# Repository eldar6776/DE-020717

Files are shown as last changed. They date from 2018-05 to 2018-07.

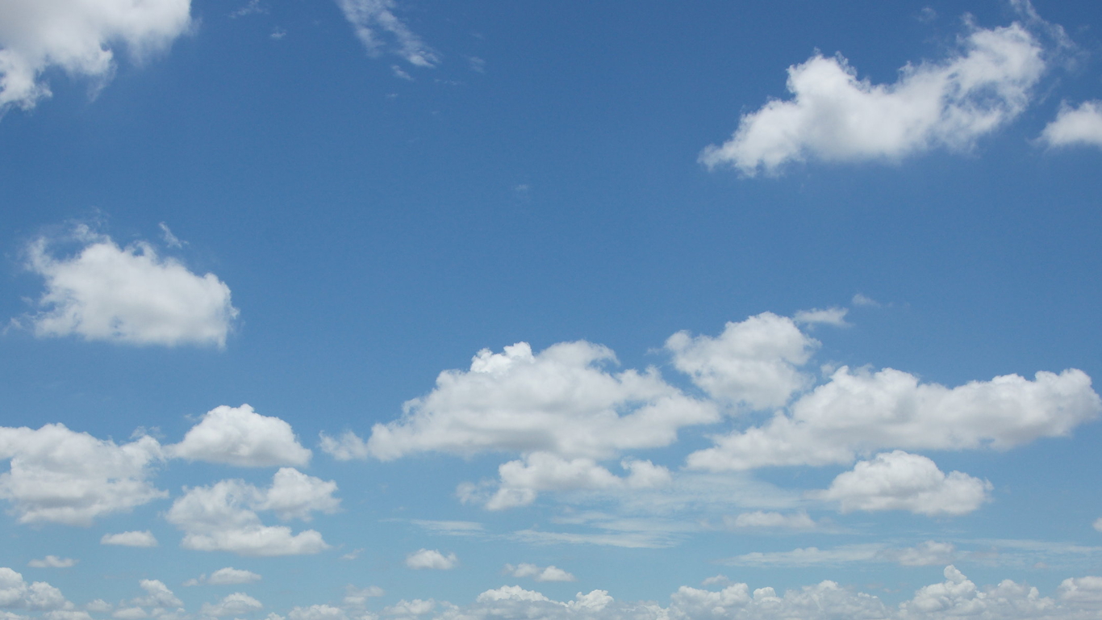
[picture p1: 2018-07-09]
doc/thermostat_gui_image/weather_cloudy_2.jpg

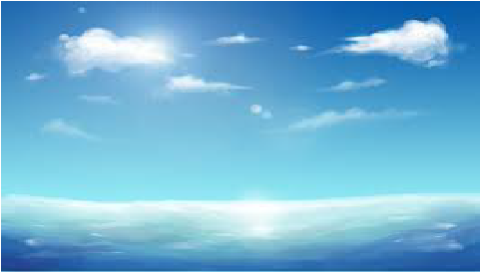
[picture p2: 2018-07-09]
doc/thermostat_gui_image/background.bmp

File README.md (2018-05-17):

# DE-020717
	Hotel Room Thermostat With Capacitive Touch 4,3" TFT LCD And Audio Codec

/**
 ******************************************************************************
 * Project Name         : DE-020717
 * Date			: 02.07.2017.
 * Hardware IDE         : Altium Designer 16.0.5
 * Firmware IDE         : KEIL uVision 5.25.0.0
 * Target Device        : STM32F746ZET  (LQFP-144, 512 Kbytes Flash, 216 MHz)
 ******************************************************************************
 * 
 * Feature		: Hardware 	
 * ----------------------------------------------------------------------------
 *	
 *	1 OneWire Serial Port For Connection With Room Control Bus Or Digital Sensors
 *	1 RS485 Serial Port For Connection With Hotel Control Bus
 *	6 Digital Otputs 0,5A 50V For Fancoil Control
 *	2 High Speed Digital Inputs Sensing Mains Phase Zero Crossing And Fan RPM
 *	3 Analog Inputs For Temperature And Light Sensing
 *	Audio Codec With Wave Player And 1W Speacker Amplifier Is Used For Audio Signal
 *	2,4GHz Radio Transciever 1Mbps For Wireless Connection To Control Network
 *	Battery Connector For RTC Backup 
 *	5Vdc Or 12Vdc Power Supply
 *	"DE-060418" Or "DE-130418" Is Used As Fancoil Interface
 *	"DE-200216" Or "DE-290817" Is Used As Room Controller 
 *	"Red Dragon 429 Demo Board" Is Used As Hotel Controller
 *
 * ----------------------------------------------------------------------------
 *	
 *			: Firmware
 * ----------------------------------------------------------------------------
 *	
 *	Room Temperature Set, Ambient Temperature Monitoring, Fancoil Fan Speed
 *	In 3 Manual Presets (Lo, Mid, Hi). Automatic Fancoil Fan Speed With PID 
 *	Control Loop When Fancoil Fan Motor Is Equipped With RPM Sensor And  
 *	Triac Is Used For Phase Control Of Fan Motor AC Power Supply. When 3 Speed
 *	Fancoil Fan Motor Is Used, Proportional Controller Is Activ In Automatic Mode.
 *	Set Thermostat For Cooling Or Heating. Software One Cycle Function Activation
 * 	Used For Room Preheating Or Precooling To Comfortable Temperature.
 *	7 Days Wheter Forecast Info Screen. Alarm Clock With One Preset.
 *	Button For "Do Not Disturb" Function Activation / Deactivation. Message Is 
 *	Displayed On Outdoor Room Controller Display And Doorbell Is Disabled.
 *	Button For "Call Handmaid" Activation / Deactivation. Signal Is Activated
 *	On Outdoor Room Controller Display And Call Is Send To Reception PC Software
 *	Button For "SOS Reset" When SOS Alarm Is Activated By Pulling SOS Switch In
 *	Bathroom.
 *
 * ----------------------------------------------------------------------------
 *
 ******************************************************************************
 */

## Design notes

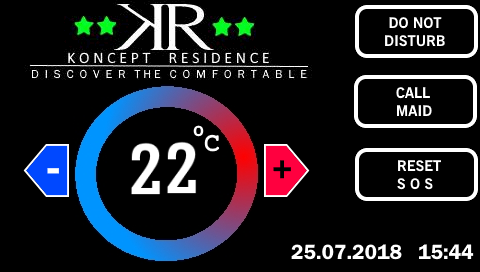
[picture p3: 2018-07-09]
doc/new_gui_image/primjer.bmp

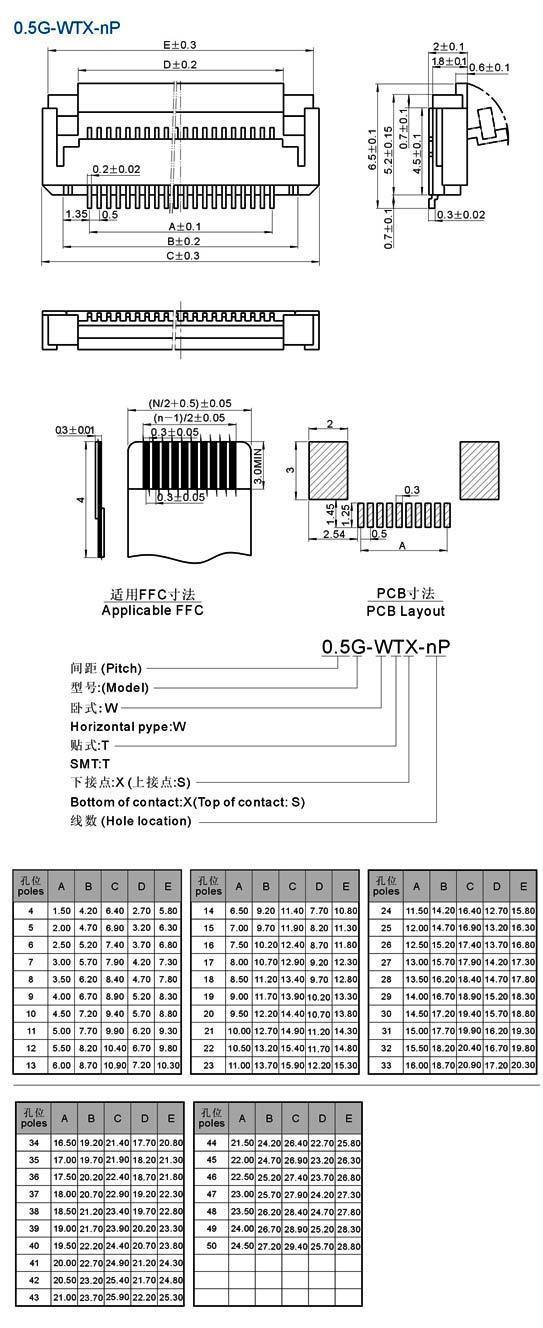
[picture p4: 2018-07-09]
doc/FPC10_Connector.jpg

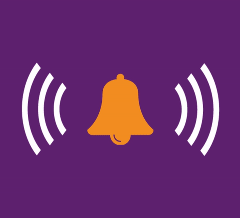
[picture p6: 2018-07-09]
doc/thermostat_gui_image/doorbell.gif

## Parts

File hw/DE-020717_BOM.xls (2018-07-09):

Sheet: BOM Report
Bill of Materials |  |  | Bill of Materials For PCB Document [DE-020717.PcbDoc]
Source Data From: |  | DE-020717.PcbDoc
Project: |  | DE-020717.PrjPcb
Variant: |  | None
Creation Date: | 2.6.2018. | 16:11:59
Print Date: | 43253 | 43253.67921
Footprint | Comment | LibRef | Designator | Description | Quantity
0603 | 100nF | C0603 | C1, C2, C3, C4, C5, C6, C7, C8, C12, C13, C14, C15, C16, C17, C19, C20, C21, C22, C23, C24, C25, C26, C27, C28, C30, C31, C32, C33, C34, C36, C37, C38, C39, C40, C41, C42, C44, C45, C46, C48, C49, C50, C51, C53, C55, C56, C66, C68, C71, C72, C74, C75, C79 | Ceramic Chip Capacitor - Standard | 59
0805 | C0805 | C0805 | C9, C10, C35 | Ceramic Chip Capacitor - Standard | 3
0603 | C0603 | C0603 | C11, C18, C29, C43, C47, C52 | Ceramic Chip Capacitor - Standard | 6
0805 | 4u7 | C0805 | C54, C57, C70, C73, C81 | Ceramic Chip Capacitor - Standard | 5
0603 | 1uF | C0603 | C67 | Ceramic Chip Capacitor - Standard | 1
3528 | 22uF/16V | 293D156X0004B2 | C83, C84 | Tantamount Commercial, Surface Mount Solid Tantalum Chip Capacitor: 15uF, 20% Tolerance, 4 WVDC @ +85°C, Surge = 5.2V | 2
3528 | 47uF/10V | 293D156X0004B2 | C85, C86 | Tantamount Commercial, Surface Mount Solid Tantalum Chip Capacitor: 15uF, 20% Tolerance, 4 WVDC @ +85°C, Surge = 5.2V | 2
3528 | 100uF | 293D156X0004B2 | C87 | Tantamount Commercial, Surface Mount Solid Tantalum Chip Capacitor: 15uF, 20% Tolerance, 4 WVDC @ +85°C, Surge = 5.2V | 1
0805 | 10uF | C0805 | C90, C93, C94 | Ceramic Chip Capacitor - Standard | 3
1.6X0.8X0.8A | HSMH-C190 | HSMH-C190 | D1 | Surface Mount Chip LED, Red | 1
ONSC-SOD-123-2-425-04_V | STPS1L40M | SMMSD301T1G | D2 | Schottky Barrier Diode, 2-Pin SOD-123, Pb-Free, Tape and Reel | 1
0603 | BLM15AG121 | Inductor_SMD | L1, L2, L3, L5, L7, L8, L9, L10 | Inductor | 8
WE-LQS 252012 | 4,7uH SMD Inductor | SMD inductor | L4 | WE-LQS SMD Power Inductor, L=4.7 µH | 1
HDR1X2 | 3VBAT | NOT FEEDED | P1 | Header, 2-Pin | 1
HDR1X2 | AMBIENT_LIGHT | NOT FEEDED | P2 | Header, 2-Pin | 1
HDR1X2 | AMBIENT_TEMPERATURE | NOT FEEDED | P3 | Header, 2-Pin | 1
10 pin PFC | TOUCH_SCREEN | TS_Connector | P4 | 10 pin PFC connector bottom contacts | 1
HDR2X4 | nRF24L01 | NOT FEEDED | P7 | Header, 4-Pin, Dual row | 1
40 pin FPC | 480x272 RGB TFT LCD AML043056B0-40 | TFT LCD Connector | P8 | 40 pin pfc connector bottom contacts | 1
HDR1X3 | ST-Link Debbuger | NOT FEEDED | P9 | Header, 3-Pin | 1
HDR2X5 | EXPAND | NOT FEEDED | P10 | Header, 5-Pin, Dual row | 1
HDR1X8 | FANCOIL_INTERFACE | NOT FEEDED | P11 | Header, 8-Pin | 1
HDR1X8 | POWER_&_COM | NOT FEEDED | P12 | Header, 8-Pin | 1
SOT23_N | 2N7002 | 2N7002 | Q1, Q2, Q3, Q4 | N-channel Enhancement Mode Vertical D-MOSFET | 4
2-0402 | 10K | ERJ2GE | R1, R2, R3, R4, R5, R6, R7, R8, R9, R10, R11, R14, R15, R16, R17, R18, R19, R20 | Thick Film Chip Resistor, 1 Ohm to 2.2M Ohm Range, 5% Tolerance, 0402 Size, 0.063 W | 18
ERA-0603 | 10K | ERA3Y | R12, R13, R22, R28, R39, R60, R61 | Rectangular Thick Film Chip Resistor, 10 Ohm to 330k Ohm Range, 0.1% and 0.5% Tolerance, 0603 Size, 0.063 W | 7
ERA-0603 | 2K7 | ERA3Y | R21, R23, R25, R26 | Rectangular Thick Film Chip Resistor, 10 Ohm to 330k Ohm Range, 0.1% and 0.5% Tolerance, 0603 Size, 0.063 W | 4
ERA-0603 | 0R | ERA3Y, ERA3Y, ERA3Y, ERA3Y, ERA3Y, ERAV | R24, R27, R34, R36, R37, R48 | Rectangular Thick Film Chip Resistor, 10 Ohm to 330k Ohm Range, 0.1% and 0.5% Tolerance, 0603 Size, 0.063 W, Rectangular Thick Film Chip Resistor, 10 Ohm to 330k Ohm Range, 0.1% and 0.5% Tolerance, 0603 Size, 0.063 W, Rectangular Thick Film Chip Resistor, | 6
ERA-0603 | 560R | ERA3Y | R29, R41 | Rectangular Thick Film Chip Resistor, 10 Ohm to 330k Ohm Range, 0.1% and 0.5% Tolerance, 0603 Size, 0.063 W | 2
ERA-0603 | 1K | ERA3Y | R30, R42, R43 | Rectangular Thick Film Chip Resistor, 10 Ohm to 330k Ohm Range, 0.1% and 0.5% Tolerance, 0603 Size, 0.063 W | 3
ERA-0603 | 330R | ERA3Y | R31 | Rectangular Thick Film Chip Resistor, 10 Ohm to 330k Ohm Range, 0.1% and 0.5% Tolerance, 0603 Size, 0.063 W | 1
ERA-0603 | NF | ERA3Y | R32, R33, R38 | Rectangular Thick Film Chip Resistor, 10 Ohm to 330k Ohm Range, 0.1% and 0.5% Tolerance, 0603 Size, 0.063 W | 3
ERA-0603 | 220R | ERA3Y | R35, R44 | Rectangular Thick Film Chip Resistor, 10 Ohm to 330k Ohm Range, 0.1% and 0.5% Tolerance, 0603 Size, 0.063 W | 2
ERA-0603 | 2K2 | ERA3Y, ERAV, ERAV, ERAV, ERAV, ERAV, ERA3Y | R40, R51, R52, R53, R54, R55, R59 | Rectangular Thick Film Chip Resistor, 10 Ohm to 330k Ohm Range, 0.1% and 0.5% Tolerance, 0603 Size, 0.063 W, Metal Film Thermosensitive Chip Resistor, 0.56 Ohm to 10k Ohm Range, 5% Tolerance, 0603 Size, 0.063 W, Metal Film Thermosensitive Chip Resistor, 0 | 7
ERA-0603 | 100K | ERAV | R45 | Metal Film Thermosensitive Chip Resistor, 0.56 Ohm to 10k Ohm Range, 5% Tolerance, 0603 Size, 0.063 W | 1
ERA-0603 | 4K7 | ERAV, ERA3Y | R46, R58 | Metal Film Thermosensitive Chip Resistor, 0.56 Ohm to 10k Ohm Range, 5% Tolerance, 0603 Size, 0.063 W, Rectangular Thick Film Chip Resistor, 10 Ohm to 330k Ohm Range, 0.1% and 0.5% Tolerance, 0603 Size, 0.063 W | 2
ERA-0805 | 10R | ERAS | R47 | Metal Film Thermosensitive Chip Resistor, 0.56 Ohm to 10k Ohm Range, 5% Tolerance, 0805 Size, 0.1 W | 1
ERA-0603 | 1K2 | ERA3Y | R57 | Rectangular Thick Film Chip Resistor, 10 Ohm to 330k Ohm Range, 0.1% and 0.5% Tolerance, 0603 Size, 0.063 W | 1
LQFP-144_20X20mm | STM32F746ZET | STM32F74XZXT | U1 | STM32F746ZET ARM Cortex M7 microcontroller | 1
MICT-P-86_N | MT48LC4M32B2P-6A | MT48LC4M32B2P-6A | U2 | 128Mb PC133 SDR SDRAM, 4Mb x 32, 6ns, 3.3V, 0 to 70 degC, 86-Pin TSOP, Pb-Free | 1
419A-01_N | MC74VHC1GT14DFT1 | MC74VHC1GT14DFT1 | U3, U5 | Schmitt-Trigger Inverter / Logic Level Shifter with LSTTL-Compatible Inputs | 2
SO16_N | ULN2003A | ULN2003D | U4 | Seven Darlington Array | 1
QFN8_V | STLD40DPUR | STLD40DPUR | U6 | White Led Power Supply For Large Display Backlight, 8-Pin VFDFPN, Tape and Reel | 1
NSO8_N | MAX485CSA | MAX485CSA | U8 | Low-Power, Slew-Rate-Limited RS-485/RS-422 Transceiver | 1
SOP8_N | M24128RMN1 | M24128RMN1 | U9 | 128 K Serial I˛C Bus EEPROM | 1
MICT-SE-8_N | N25Q128A13ESE40E | N25Q128A13ESE40E | U10 | 128 Mb (x1/x2/x4) Serial NOR Flash Memory with Multi I/O, 108 MHz, 2.7 to 3.6 V, 8-pin SO8 Wide (SE), Tray | 1
TO220 | DC/DC BUCK | NOT FEEDED | U11 | Positive Voltage Regulator, 5V, 3-Pin TO-220 | 1
ZZ311 | REG1117-3.3 | REG1117-3.3 | U12 | 800mA and 1A Low Dropout Positive Regulator 2.85V, 3.3V, 5V, and Adjustable | 1
CSM-7 | ECS-110-S-5P | 8MHz | Y1 | Crystal Oscillator | 1
R38 | RTC | 32,768kHz | Y2 | Crystal Oscillator | 1
 |  |  |  |  | 178
Approved |  | Notes

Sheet: Project Information
Project Full Path | F:\SkyDrive\OtvoreniProjekti\HotelSaplast\hw\DE-020717\DE-020717.PrjPcb
Project Filename | DE-020717.PrjPcb
Variant Name | None
Data-Source Filename | DE-020717.PcbDoc
Data-Source Full Path | F:\SkyDrive\OtvoreniProjekti\HotelSaplast\hw\DE-020717\DE-020717.PcbDoc
Title | Bill of Materials For PCB Document [DE-020717.PcbDoc]
Total Quantity | 178
Report Time | 16:11:59
Report Date | 2.6.2018.
Report Date & Tine | 2.6.2018. 16:11:59
Output Name | Bill of Materials
Output Type | BOM_PartType
Output Generator Name | BOM
Output Generator Description | Bill of Materials

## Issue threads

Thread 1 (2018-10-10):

w25q?

rockcastle, 2018-10-10:
Hi,
I have been working on  w25q128fv and N25Q, QSPI modules on stm32f767, I am stuck with having stldr. I had couple of them but don't work. The one under STMCubeProgrammers external stldr is N25Q is working but when i compile and try to upload it does not work. Could you help me please?
Thanks

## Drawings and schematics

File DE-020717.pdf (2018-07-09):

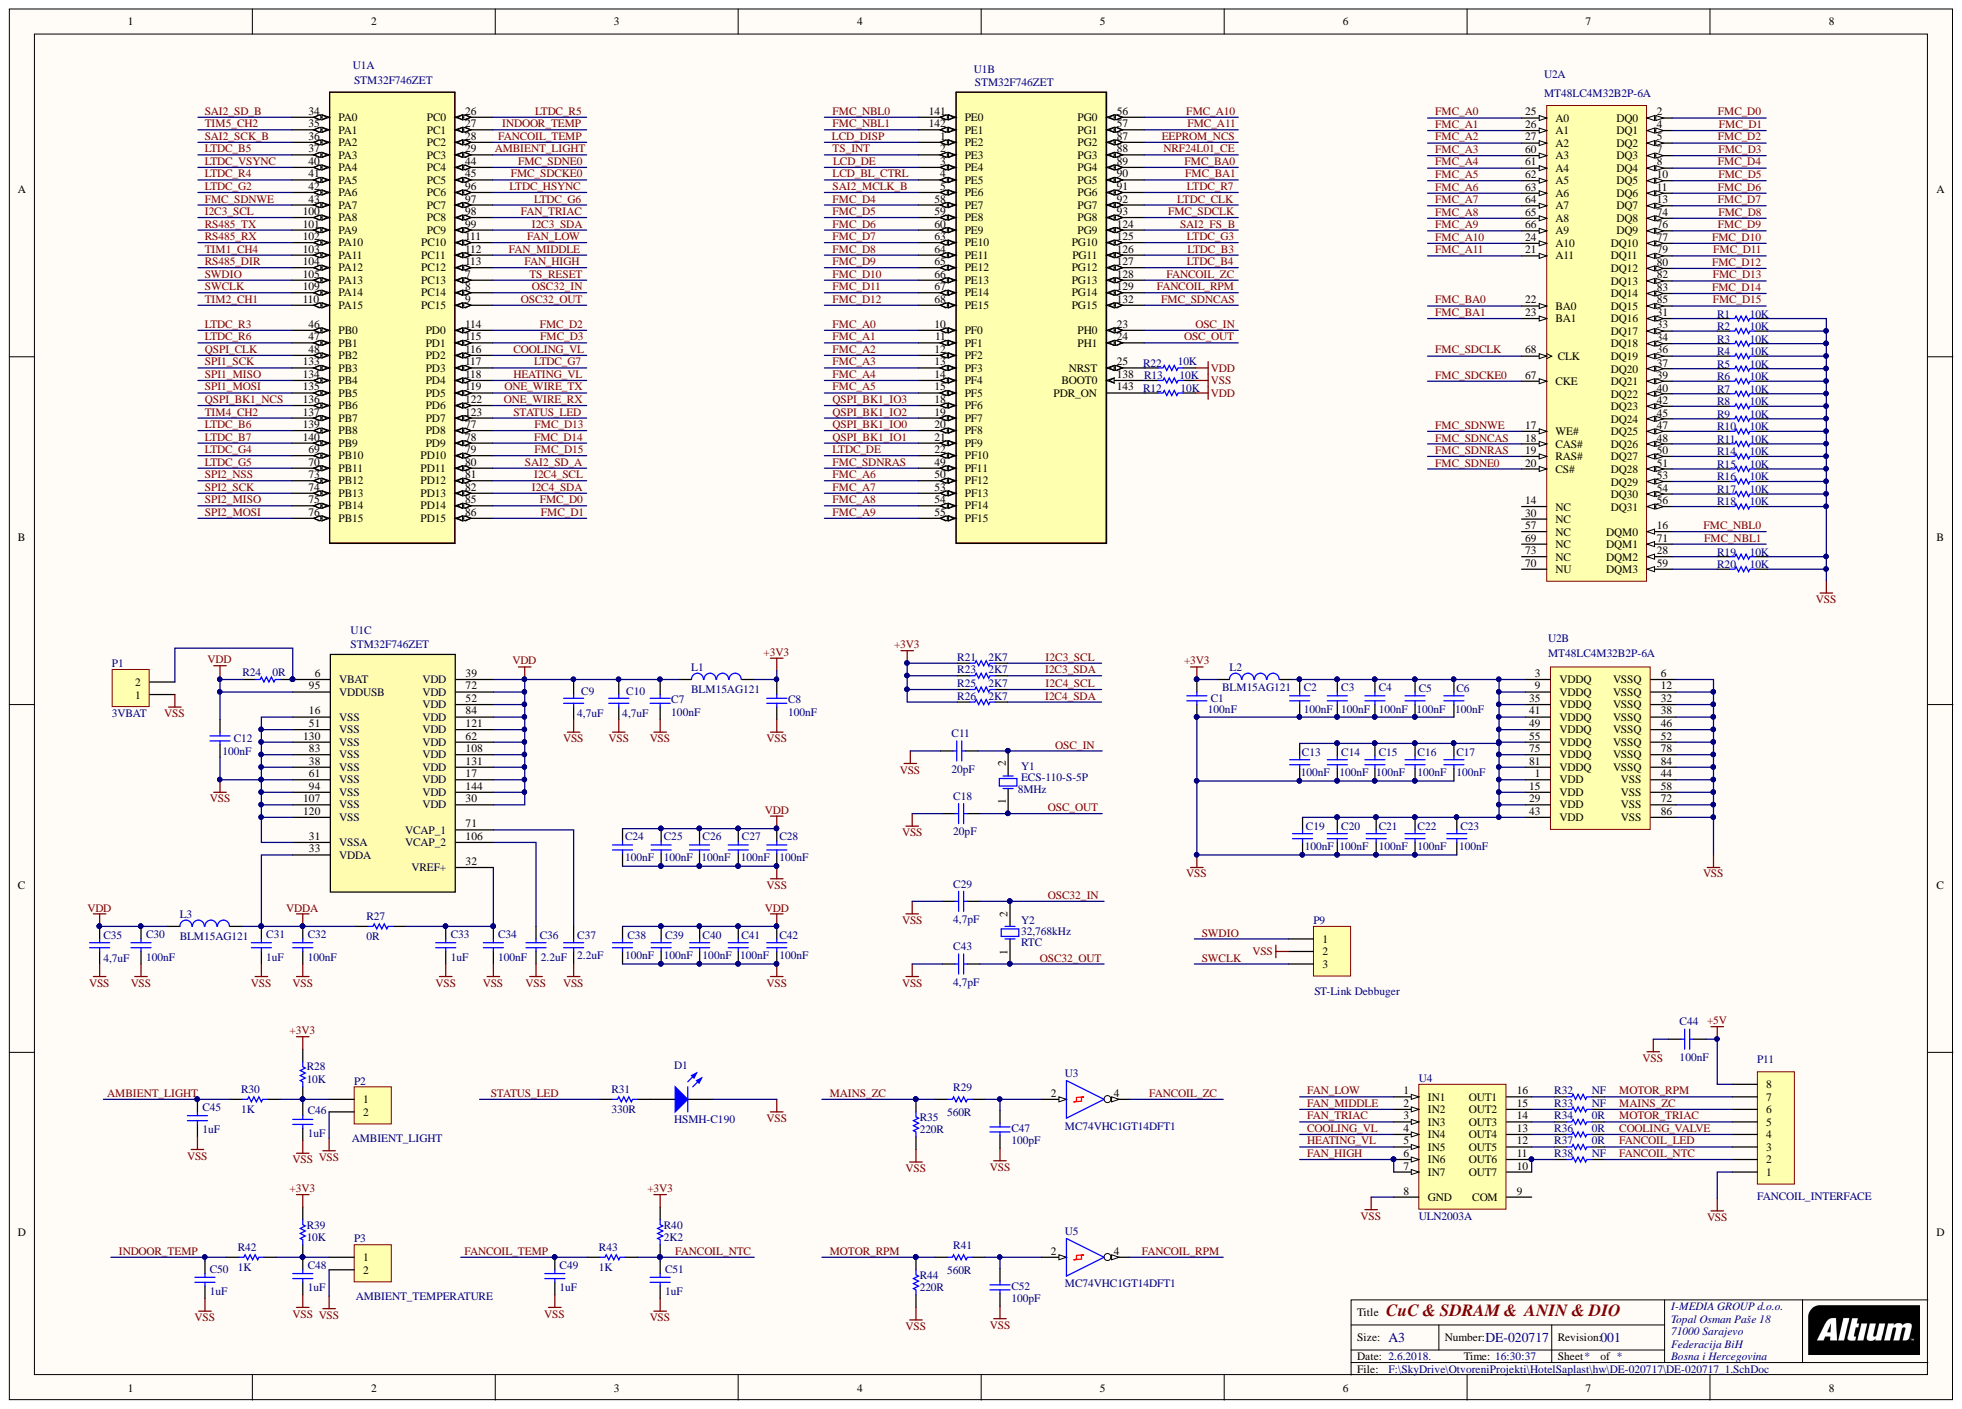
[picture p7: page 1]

NC 69 | FMC_NBL1
NC 73 | R19 10K
NU 70 | R20 10K

CuC & SDRAM & ANIN & DIO Title | I-MEDIA GROUP d.o.o. Topal Osman Paše 18 71000 Sarajevo Federacija BiH Bosna i Hercegovina

Size: A3 | Number: DE-020717 | Revision: 001
Date: 2.6.2018. Time: 16:30:37 | | Sheet * of *

F:\SkyDrive\OtvoreniProjekti\HotelSaplast\hw\DE-020717\DE-020717_1.SchDoc

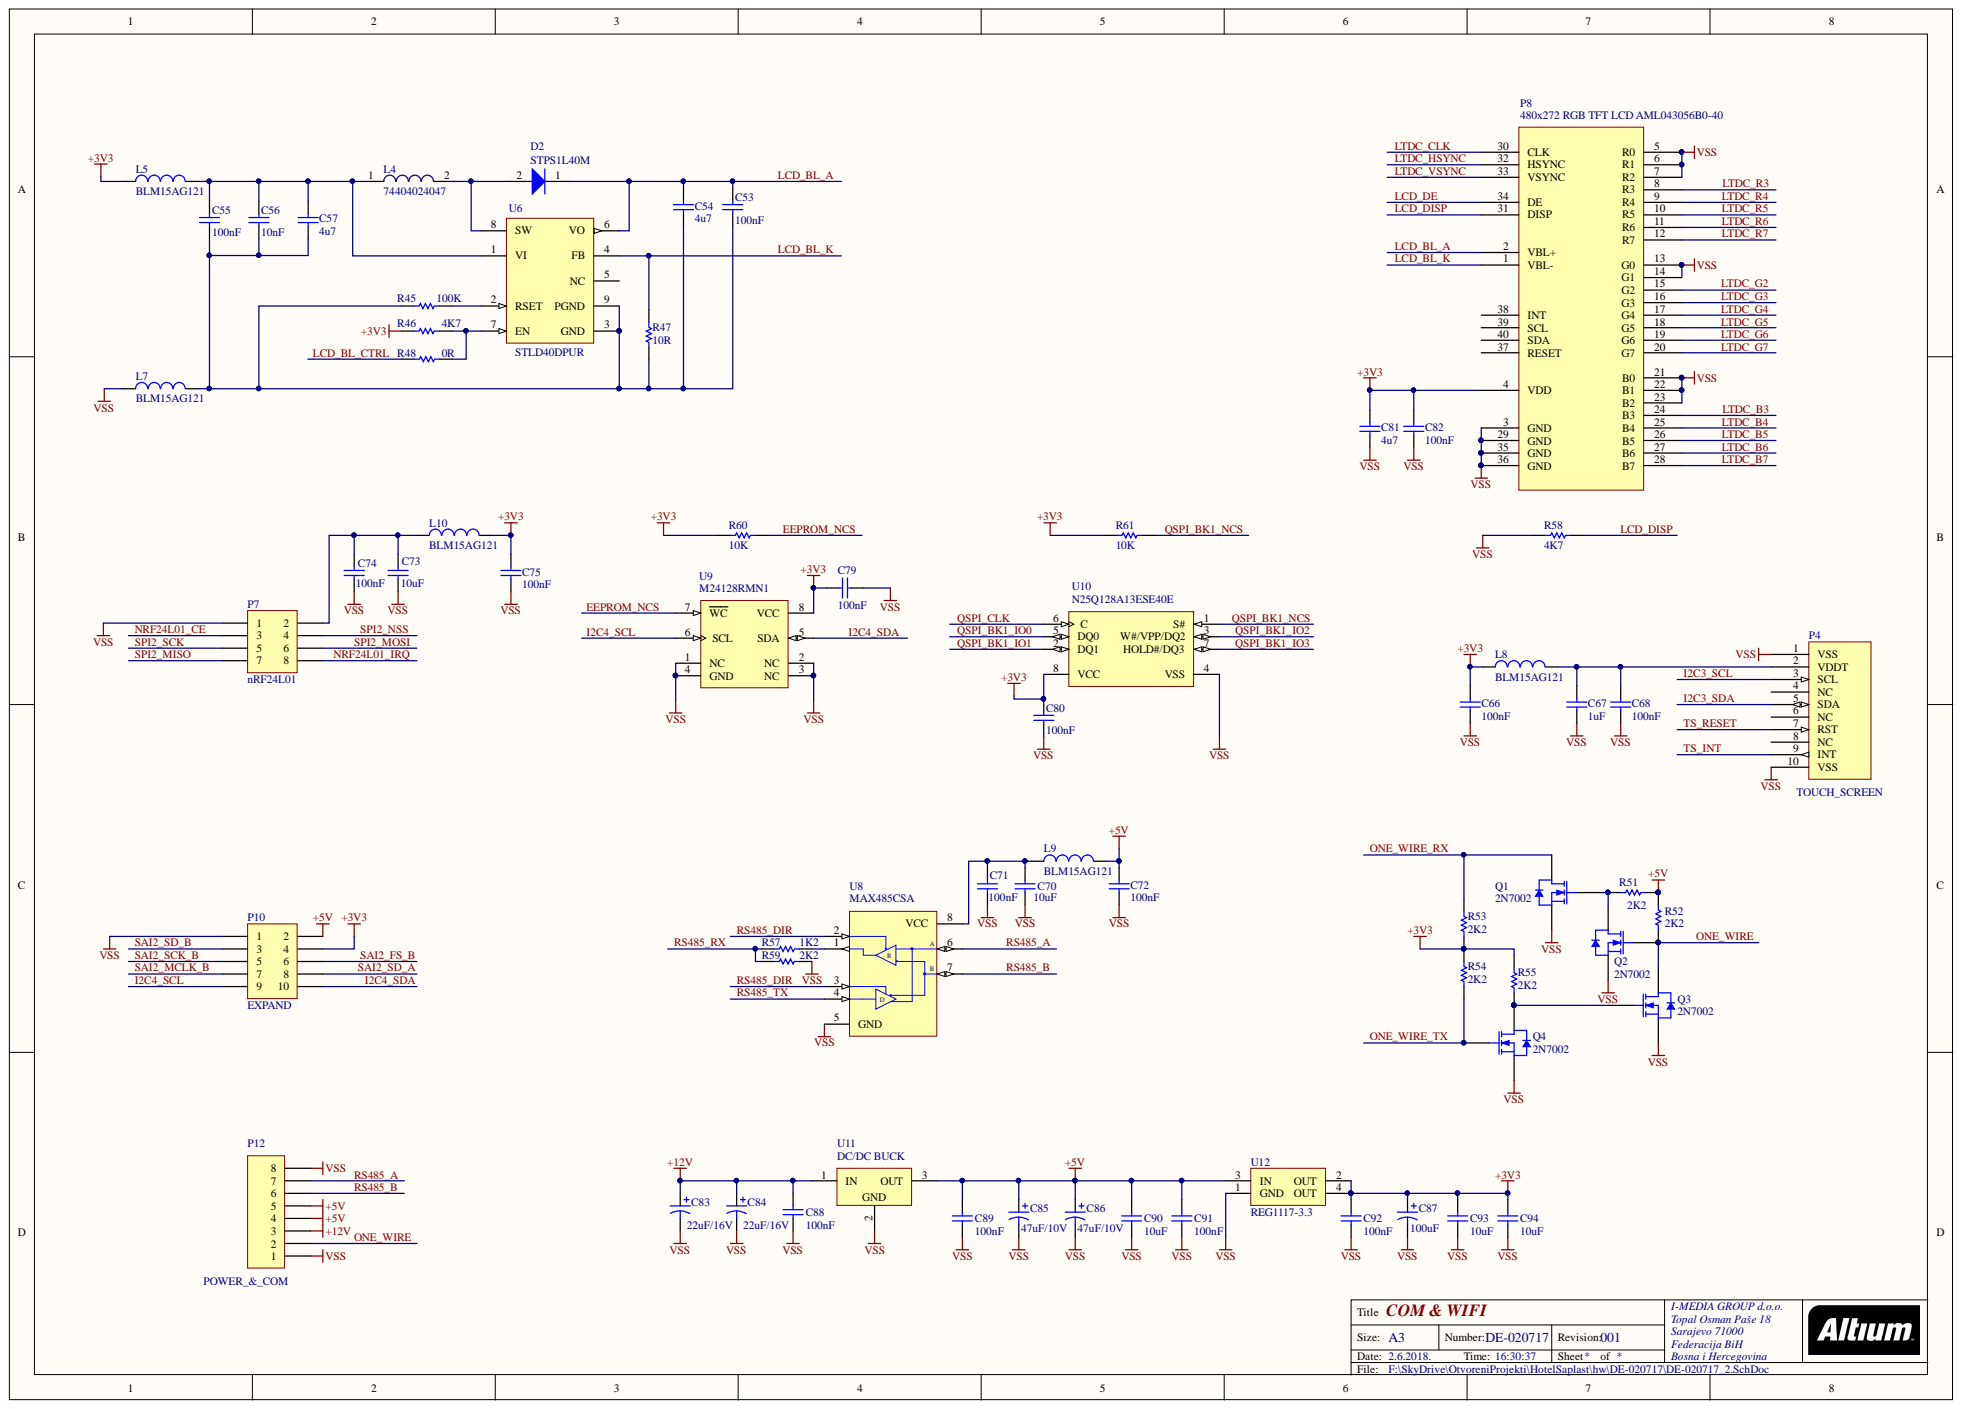
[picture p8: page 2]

COM & WIFI Title | I-MEDIA GROUP d.o.o. Topal Osman Paše 18 Sarajevo 71000 Federacija BiH Bosna i Hercegovina

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

F:\SkyDrive\OtvoreniProjekti\HotelSaplast\hw\DE-020717\DE-020717_2.SchDoc

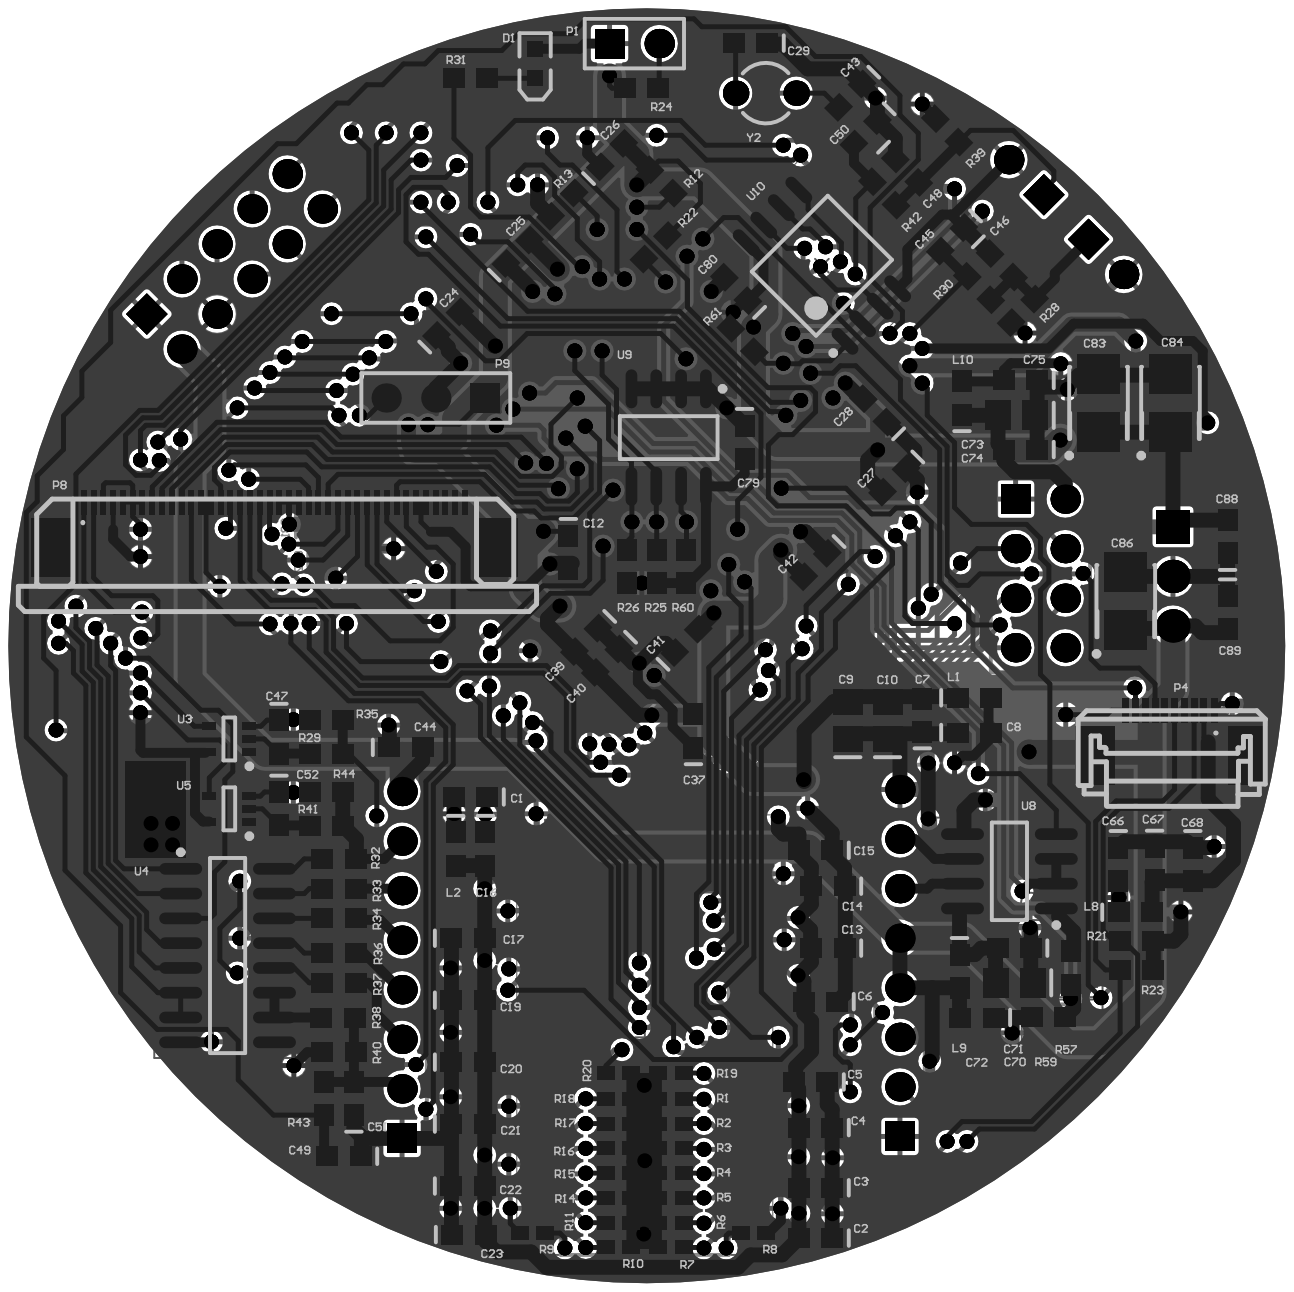
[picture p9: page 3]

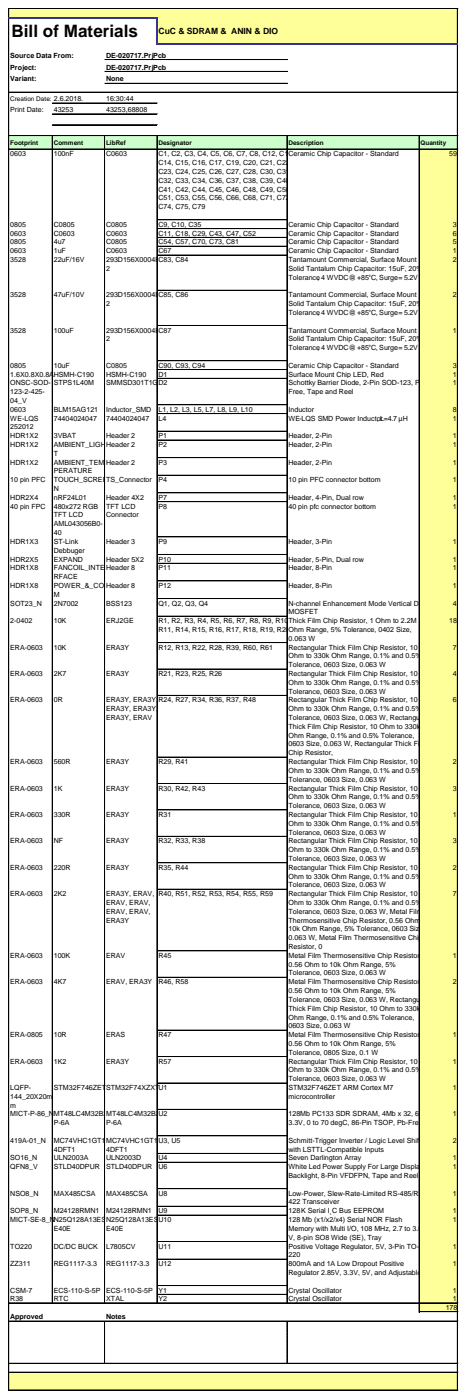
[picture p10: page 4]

Footprint | Comment | LibRef | Designator | Description | Quantity

Solid Tantalum Chip Capacitor: 15uF, 20%
Tolerance, 4 WVDC @ +85°C, Surge = 5.2V

Free, Tape and Reel

MOSFET
Thick Film Chip Resistor, 1 Ohm to 2.2M
Ohm Range, 5% Tolerance, 0402 Size,

Ohm to 330k Ohm Range, 0.1% and 0.5%
Tolerance, 0603 Size, 0.063 W

Tolerance, 0603 Size, 0.063 W, Rectangular
Thick Film Chip Resistor, 10 Ohm to 330k
Ohm Range, 0.1% and 0.5% Tolerance,
0603 Size, 0.063 W, Rectangular Thick Film
Chip Resistor,

Tolerance, 0603 Size, 0.063 W, Metal Film
Thermosensitive Chip Resistor, 0.56 Ohm
10k Ohm Range, 5% Tolerance, 0603 Siz
0.063 W, Metal Film Thermosensitive Chip
Resistor, 0

0.56 Ohm to 10k Ohm Range, 5%

0603 Size, 0.063 W

Tolerance, 0805 Size, 0.1 W

3.3V, 0 to 70 degC, 86-Pin TSOP, Pb-Free

with LSTTL-Compatible Inputs

Backlight, 8-Pin VFDFPN, Tape and Reel

Memory with Multi I/O, 108 MHz, 2.7 to 3.6
V, 8-pin SO8 Wide (SE), Tray

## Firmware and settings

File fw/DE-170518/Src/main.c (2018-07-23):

/**
 ******************************************************************************
 * File Name          : main.c
 * Date               : 10.3.2018.
 * Description        : Hotel Room Thermostat Program Code
 ******************************************************************************
 *
 *
 ******************************************************************************
 */


/* Includes ------------------------------------------------------------------*/
#include "WM.h"
#include "GUI.h"
#include <math.h>
#include "main.h"
#include "common.h"
#include "display.h"
#include "one_wire.h"
#include "thermostat.h"
//#include "waveplayer.h"
#include "stm32746g.h"
#include "stm32746g_ts.h"
#include "stm32746g_qspi.h"
#include "stm32746g_sdram.h"
#include "stm32746g_audio.h"
#include "stm32746g_eeprom.h"


/* Imported Type  ------------------------------------------------------------*/
/* Imported Variable  --------------------------------------------------------*/
/* Imported Function  --------------------------------------------------------*/
/* Private Type --------------------------------------------------------------*/
ADC_HandleTypeDef hadc3;
UART_HandleTypeDef huart2;
TIM_HandleTypeDef htim3;
TIM_HandleTypeDef htim9;
I2C_HandleTypeDef hi2c4;
I2C_HandleTypeDef hi2c3;
LTDC_HandleTypeDef hltdc;
DMA2D_HandleTypeDef hdma2d;
CRC_HandleTypeDef hcrc;
RTC_HandleTypeDef hrtc;
RTC_TimeTypeDef time;
RTC_DateTypeDef date;
#ifndef	USE_DEBUGGER
IWDG_HandleTypeDef hiwdg;
#endif

/* Private Define ------------------------------------------------------------*/
#define TOUCH_SCREEN_UPDATE_TIME			22		// 5ms touch screen update period
#define TOUCH_SCREEN_LAYER                  1       // touch screen layer event
#define AMBIENT_NTC_RREF                    10000  	// 10k NTC value of at 25 degrees
#define AMBIENT_NTC_B_VALUE                 3977 	// NTC beta parameter
#define AMBIENT_NTC_PULLUP                  10000	// 10k pullup resistor
#define FANCOIL_NTC_RREF                    2000  	// 2k fancoil NTC value of at 25 degrees
#define FANCOIL_NTC_B_VALUE                 3950 	// NTC beta parameter
#define FANCOIL_NTC_PULLUP                  2200	// 2k2 pullup resistor
#define ADC_READOUT_PERIOD                  123      // 89 ms ntc conversion rate
#define FAN_CONTROL_LOOP_PERIOD			    200	    // fan speed control loop 
#define BUZZER_BUTTON_TIME                  50
#define BUZZER_BIP_TIME                     100
#define BUZZER_SHORT_TIME                   500 
#define BUZZER_LONG_TIME                    1000
#define TRIAC_ON_PULSE                      5       // 500 us triac on pulse duration
#define SYSTEM_STARTUP_TIME                 10000    // 12s system startup config check


/* Private Variable ----------------------------------------------------------*/
__IO uint32_t SystickCnt;
__IO uint32_t sys_flags;
__IO uint32_t sys_timer;
__IO uint32_t anin_timer;
__IO uint32_t fancoil_ntc_timer;

uint32_t triac_timer;
uint32_t triac_on_time;
uint32_t fan_rpm_timer;
uint32_t fan_rpm_pulse;

uint16_t ambient_ntc_b_value = AMBIENT_NTC_B_VALUE;
uint16_t fancoil_ntc_b_value = FANCOIL_NTC_B_VALUE;
uint16_t fancoil_ntc_temperature;
uint16_t ambient_ntc_temperature;
uint16_t ambient_light;
uint16_t ts_update_timer;
uint16_t rtc_bckp_tmr;


uint32_t buzzer_repeat_timer;
uint32_t buzzer_mode_timer;
uint8_t buzzer_repeat_time;
uint8_t buzzer_mode;
uint8_t buzzer_pcnt;

uint8_t ambient_ntc_temperature_sample_cnt;
uint8_t fancoil_ntc_temperature_sample_cnt;
uint8_t ambient_light_sample_cnt;
uint8_t zero_cross_cnt;


uint16_t ambient_ntc_temperature_sample_value[10] = {
	2100, 2100, 2100, 2100, 2100, 
	2100, 2100, 2100, 2100, 2100
};

uint16_t fancoil_ntc_temperature_sample_value[10] = {
	2100, 2100, 2100, 2100, 2100, 
	2100, 2100, 2100, 2100, 2100
};

uint16_t ambient_light_sample_value[10] = {
	2100, 2100, 2100, 2100, 2100, 
	2100, 2100, 2100, 2100, 2100
};

uint8_t RTC_Months[2][12] = {
	{31, 28, 31, 30, 31, 30, 31, 31, 30, 31, 30, 31},	/* Not leap year */
	{31, 29, 31, 30, 31, 30, 31, 31, 30, 31, 30, 31}	/* Leap year */
};


/* Private Macro -------------------------------------------------------------*/
#define RTC_LEAP_YEAR(year)             ((((year) % 4 == 0) && ((year) % 100 != 0)) || ((year) % 400 == 0))
#define RTC_DAYS_IN_YEAR(x)             RTC_LEAP_YEAR(x) ? 366 : 365
#define RTC_BCD2BIN(x)                  ((((x) >> 4) & 0x0F) * 10 + ((x) & 0x0F))
#define RTC_CHAR2NUM(x)                 ((x) - '0')
#define RTC_CHARISNUM(x)                ((x) >= '0' && (x) <= '9')


/* Private Function Prototype ------------------------------------------------*/
static void MPU_Config(void);
static void CACHE_Config(void);
static void SystemClock_Config(void);
#ifndef	USE_DEBUGGER
void MX_IWDG_Init(void);
#endif
static void MX_GPIO_Init(void);
static void MX_CRC_Init(void);
static void MX_RTC_Init(void);
static void MX_TIM3_Init(void);
static void MX_TIM9_Init(void);
static void MX_UART2_Init(void);
static void MX_ADC3_Init(void);
static void ADC3_Read(void);
void TouchUpdate(void);
void BootloaderExe(void);
void Error_Handler(void);
float AMBIENT_NTC_GetResistance(uint16_t adc_value);
float AMBIENT_NTC_GetTemperature(float ntc_resistance);
float FANCOIL_NTC_GetResistance(uint16_t adc_value);
float FANCOIL_NTC_GetTemperature(float ntc_resistance);


/* Program Code  -------------------------------------------------------------*/
int main(void)
{
    SYSTEM_StartTimer(SYSTEM_STARTUP_TIME);
	MPU_Config();
	CACHE_Config();
	HAL_Init(); 
	SystemClock_Config();
#ifndef	USE_DEBUGGER
	MX_IWDG_Init();
#endif	
    MX_CRC_Init();
	MX_RTC_Init();
	MX_ADC3_Init();
	MX_UART2_Init();
	MX_TIM3_Init();
	MX_TIM9_Init();
	MX_GPIO_Init();
	MX_QSPI_Init();
    BSP_EEPROM_Init();
    TOUCH_SCREEN_Init(480, 272);
	SDRAM_Init();
	DISPLAY_Init();
	ONEWIRE_Init();
	THERMOSTAT_Init();
    
    
#ifndef	USE_DEBUGGER
	HAL_IWDG_Refresh(&hiwdg);
#endif

	while(1)
	{
        ADC3_Read();
		ONEWIRE_Service();
		THERMOSTAT_Service();
		DISPLAY_Service();
#ifndef	USE_DEBUGGER
        HAL_IWDG_Refresh(&hiwdg);
#endif
	}
}


static void MPU_Config(void)
{
	MPU_Region_InitTypeDef MPU_InitStruct;

	/* Disable the MPU */
	HAL_MPU_Disable();

	/* Configure the MPU attributes as WT for SRAM */
	MPU_InitStruct.Enable           = MPU_REGION_ENABLE;
	MPU_InitStruct.BaseAddress      = 0x20010000;
	MPU_InitStruct.Size             = MPU_REGION_SIZE_256KB;
	MPU_InitStruct.AccessPermission = MPU_REGION_FULL_ACCESS;
	MPU_InitStruct.IsBufferable     = MPU_ACCESS_NOT_BUFFERABLE;
	MPU_InitStruct.IsCacheable      = MPU_ACCESS_CACHEABLE;
	MPU_InitStruct.IsShareable      = MPU_ACCESS_SHAREABLE;
	MPU_InitStruct.Number           = MPU_REGION_NUMBER0;
	MPU_InitStruct.TypeExtField     = MPU_TEX_LEVEL0;
	MPU_InitStruct.SubRegionDisable = 0x00;
	MPU_InitStruct.DisableExec      = MPU_INSTRUCTION_ACCESS_ENABLE;
	HAL_MPU_ConfigRegion(&MPU_InitStruct);

	/* Configure the MPU attributes for Quad-SPI area to strongly ordered
	 This setting is essentially needed to avoid MCU blockings! 
	 See also STM Application Note AN4861 */
	MPU_InitStruct.Enable           = MPU_REGION_ENABLE;
	MPU_InitStruct.Number           = MPU_REGION_NUMBER2;
	MPU_InitStruct.BaseAddress      = 0x90000000;
	MPU_InitStruct.Size             = MPU_REGION_SIZE_256MB;
	MPU_InitStruct.SubRegionDisable = 0x0;
	MPU_InitStruct.TypeExtField     = MPU_TEX_LEVEL0;
	MPU_InitStruct.AccessPermission = MPU_REGION_NO_ACCESS;
	MPU_InitStruct.DisableExec      = MPU_INSTRUCTION_ACCESS_DISABLE;
	MPU_InitStruct.IsShareable      = MPU_ACCESS_SHAREABLE;
	MPU_InitStruct.IsCacheable      = MPU_ACCESS_NOT_CACHEABLE;
	MPU_InitStruct.IsBufferable     = MPU_ACCESS_NOT_BUFFERABLE;
	HAL_MPU_ConfigRegion(&MPU_InitStruct);

	/* Configure the MPU attributes for the QSPI 64MB to normal memory Cacheable, must reflect the real memory size */
	MPU_InitStruct.Enable           = MPU_REGION_ENABLE;
	MPU_InitStruct.Number           = MPU_REGION_NUMBER3;
	MPU_InitStruct.BaseAddress      = 0x90000000;
	MPU_InitStruct.Size             = MPU_REGION_SIZE_16MB; // Set region size according to the QSPI memory size
	MPU_InitStruct.SubRegionDisable = 0x0;
	MPU_InitStruct.TypeExtField     = MPU_TEX_LEVEL0;
	MPU_InitStruct.AccessPermission = MPU_REGION_FULL_ACCESS;
	MPU_InitStruct.DisableExec      = MPU_INSTRUCTION_ACCESS_DISABLE;
	MPU_InitStruct.IsShareable      = MPU_ACCESS_SHAREABLE;
	MPU_InitStruct.IsCacheable      = MPU_ACCESS_CACHEABLE;
	MPU_InitStruct.IsBufferable     = MPU_ACCESS_NOT_BUFFERABLE;
	HAL_MPU_ConfigRegion(&MPU_InitStruct);

	/* Configure the MPU attributes for SDRAM_Banks area to strongly ordered
	 This setting is essentially needed to avoid MCU blockings!
	 See also STM Application Note AN4861 */
	MPU_InitStruct.Enable           = MPU_REGION_ENABLE;
	MPU_InitStruct.Number           = MPU_REGION_NUMBER4;
	MPU_InitStruct.BaseAddress      = 0xC0000000;
	MPU_InitStruct.Size             = MPU_REGION_SIZE_512MB;
	MPU_InitStruct.SubRegionDisable = 0x0;
	MPU_InitStruct.TypeExtField     = MPU_TEX_LEVEL0;
	MPU_InitStruct.AccessPermission = MPU_REGION_NO_ACCESS;
	MPU_InitStruct.DisableExec      = MPU_INSTRUCTION_ACCESS_DISABLE;
	MPU_InitStruct.IsShareable      = MPU_ACCESS_SHAREABLE;
	MPU_InitStruct.IsCacheable      = MPU_ACCESS_NOT_CACHEABLE;
	MPU_InitStruct.IsBufferable     = MPU_ACCESS_NOT_BUFFERABLE;
	HAL_MPU_ConfigRegion(&MPU_InitStruct);

	/* Configure the MPU attributes for SDRAM 16MB to normal memory Cacheable */
	MPU_InitStruct.Enable           = MPU_REGION_ENABLE;
	MPU_InitStruct.Number           = MPU_REGION_NUMBER5;
	MPU_InitStruct.BaseAddress      = 0xC0000000;
	MPU_InitStruct.Size             = MPU_REGION_SIZE_8MB;
	MPU_InitStruct.SubRegionDisable = 0x0;
	MPU_InitStruct.TypeExtField     = MPU_TEX_LEVEL0;
	MPU_InitStruct.AccessPermission = MPU_REGION_FULL_ACCESS;
	MPU_InitStruct.DisableExec      = MPU_INSTRUCTION_ACCESS_ENABLE;
	MPU_InitStruct.IsShareable      = MPU_ACCESS_SHAREABLE;
	MPU_InitStruct.IsCacheable      = MPU_ACCESS_CACHEABLE;
	MPU_InitStruct.IsBufferable     = MPU_ACCESS_NOT_BUFFERABLE;
	HAL_MPU_ConfigRegion(&MPU_InitStruct);

	/* Enable the MPU */
	HAL_MPU_Enable(MPU_PRIVILEGED_DEFAULT);
	
	/* Disable FMC bank1 (0x6000 0000 - 0x6FFF FFFF), since it is not used.
	This setting avoids unnedded speculative access to the first FMC bank.
	See also STM Application Note AN4861 */
	FMC_Bank1->BTCR[0] = 0x000030D2;
}

static void CACHE_Config(void)
{
	SCB_EnableICache();
	SCB_EnableDCache();	
}


void HAL_SYSTICK_Callback(void)
{
    if(sys_timer) --sys_timer;
    else SYSTEM_StartupReset();
    
    if(IsBUZZER_SignalActiv())
	{
        switch (buzzer_mode)
        {
            case BUZZER_MODE_OFF:
            {
                buzzer_pcnt = 0;
                BUZZER_SignalOff();
                break;
            }
            
            case BUZZER_MODE_BIP:
            {
                if((buzzer_pcnt == 0) && IsBUZZER_ModeTimerExpired())
                {
                    if(IsBUZZER_RepeatTimerExpired())
                    {
                        BUZZER_On();
                        BUZZER_StartModeTimer(BUZZER_BIP_TIME);
                        ++buzzer_pcnt;                        
                    }
                }
                else if((buzzer_pcnt == 1) && IsBUZZER_ModeTimerExpired())
                {
                    BUZZER_Off();
                    buzzer_pcnt = 0;
                    if(buzzer_repeat_time == 0) BUZZER_StartModeTimer(BUZZER_BIP_TIME);
                    else BUZZER_StartRepeatTimer(buzzer_repeat_time * 1000);
                }
                break;
            }
            
            case BUZZER_MODE_SHORT:
            {
                if((buzzer_pcnt == 0) && IsBUZZER_ModeTimerExpired())
                {
                    if(IsBUZZER_RepeatTimerExpired())
                    {
                        BUZZER_On();
                        BUZZER_StartModeTimer(BUZZER_SHORT_TIME);
                        ++buzzer_pcnt;                        
                    }
                }
                else if((buzzer_pcnt == 1) && IsBUZZER_ModeTimerExpired())
                {
                    BUZZER_Off();
                    buzzer_pcnt = 0;
                    if(buzzer_repeat_time == 0) BUZZER_StartModeTimer(BUZZER_SHORT_TIME);
                    else BUZZER_StartRepeatTimer(buzzer_repeat_time * 1000);
                }
                break;
            }
            
            case BUZZER_MODE_LONG:
            {
                if((buzzer_pcnt == 0) && IsBUZZER_ModeTimerExpired())
                {
                    if(IsBUZZER_RepeatTimerExpired())
                    {
                        BUZZER_On();
                        BUZZER_StartModeTimer(BUZZER_LONG_TIME);
                        ++buzzer_pcnt;                        
                    }
                }
                else if((buzzer_pcnt == 1) && IsBUZZER_ModeTimerExpired())
                {
                    BUZZER_Off();
                    buzzer_pcnt = 0;
                    if(buzzer_repeat_time == 0) BUZZER_StartModeTimer(BUZZER_LONG_TIME);
                    else BUZZER_StartRepeatTimer(buzzer_repeat_time * 1000);
                }
                break;
            }
            
            case BUZZER_BUTTON_PRESSED:
            {
                if(buzzer_pcnt == 0)
                {
                    BUZZER_On();
                    BUZZER_StartModeTimer(BUZZER_BUTTON_TIME);
                    ++buzzer_pcnt;
                }
                else if((buzzer_pcnt == 1) && IsBUZZER_ModeTimerExpired())
                {
                    BUZZER_Off();
                    buzzer_mode = BUZZER_MODE_OFF;
                }
                break;
            }
            default:
            {
                BUZZER_SignalOff();
                break;
            }
        }
	}
    else
    {
        BUZZER_StopRepeatTimer();
        BUZZER_StopModeTimer();
        BUZZER_SignalOff();
        BUZZER_RepeatTimerReset();
        buzzer_pcnt = 0;
        BUZZER_Off();
    }
    
    if (IsFANCOIL_CoolingValveOn()) ++fancoil_ntc_timer;
    else fancoil_ntc_timer = 0;
	
	if(hadc3.Instance == ADC3)
	{
		if (anin_timer) --anin_timer;
	}
	
	if(IsTOUCH_SCREEN_Enabled())
	{
		if(ts_update_timer == 0)
		{
			TouchUpdate();
			ts_update_timer = TOUCH_SCREEN_UPDATE_TIME;
		}
        else --ts_update_timer;
	}	
	
	if(onewire_timer) --onewire_timer;
	if(thermostat_timer) --thermostat_timer;
	if(thermostat_fan_timer) --thermostat_fan_timer;
	if(valve_timer) --valve_timer;
	if(display_timer) --display_timer;
	if(display_date_time_timer) --display_date_time_timer;
    if(display_screensaver_timer) --display_screensaver_timer;
	if(display_message_timer) --display_message_timer;
	if(buzzer_mode_timer) --buzzer_mode_timer;
    if(buzzer_repeat_timer) --buzzer_repeat_timer;
    
    if(onewire_timeout_timer)
    {
        if(--onewire_timeout_timer == 0) OnewireState = ONEWIRE_RECEIVE;
    }
    
    
    if(fan_rpm_timer) 
    {
        if(--fan_rpm_timer == 0)
        {
            /*  run fancoil fan motor shortly with triac driver to sense hall rpm sensor if available, 
            *   this will define functions used to controll hardware interface and type of temperature controller
            *   rpm sensor will be also used for cleaning request when motor start to slow down due to dust collect
            *   if sensor not available,than tree speed motor is used for fancoil fan, and controller is simpler without
            *   precise timings for triac triggering releasing from runtime code two interrupt request services
            */ 
            if(IsSYSTEM_StartupActiv() && (fan_rpm_pulse > 10)) FANCOIL_RPM_SensorConnected();
            else if(IsFANCOIL_RPM_SensorConnected() && (fan_rpm_pulse < 10)) FANCOIL_RPM_SensorErrorSet();            
        }
    }
}

static void SystemClock_Config(void)
{
	RCC_OscInitTypeDef RCC_OscInitStruct;
	RCC_ClkInitTypeDef RCC_ClkInitStruct;
	RCC_PeriphCLKInitTypeDef PeriphClkInitStruct;

	/**Configure the main internal regulator output voltage 
	*/
	__HAL_RCC_PWR_CLK_ENABLE();

	__HAL_PWR_VOLTAGESCALING_CONFIG(PWR_REGULATOR_VOLTAGE_SCALE1);

	/**Initializes the CPU, AHB and APB busses clocks 
	*/
	RCC_OscInitStruct.OscillatorType = RCC_OSCILLATORTYPE_HSE|RCC_OSCILLATORTYPE_LSE;
	RCC_OscInitStruct.HSEState = RCC_HSE_ON;
	RCC_OscInitStruct.LSEState = RCC_LSE_ON;
	RCC_OscInitStruct.PLL.PLLState = RCC_PLL_ON;
	RCC_OscInitStruct.PLL.PLLSource = RCC_PLLSOURCE_HSE;
	RCC_OscInitStruct.PLL.PLLM = 4;
	RCC_OscInitStruct.PLL.PLLN = 200;
	RCC_OscInitStruct.PLL.PLLP = RCC_PLLP_DIV2;
	RCC_OscInitStruct.PLL.PLLQ = 2;
	
	if (HAL_RCC_OscConfig(&RCC_OscInitStruct) != HAL_OK)
	{
		Error_Handler();
	}

	/**Activate the Over-Drive mode 
	*/
	if (HAL_PWREx_EnableOverDrive() != HAL_OK)
	{
		Error_Handler();
	}

	/**Initializes the CPU, AHB and APB busses clocks 
	*/
	RCC_ClkInitStruct.ClockType = RCC_CLOCKTYPE_HCLK|RCC_CLOCKTYPE_SYSCLK
							  |RCC_CLOCKTYPE_PCLK1|RCC_CLOCKTYPE_PCLK2;
	RCC_ClkInitStruct.SYSCLKSource = RCC_SYSCLKSOURCE_PLLCLK;
	RCC_ClkInitStruct.AHBCLKDivider = RCC_SYSCLK_DIV1;
	RCC_ClkInitStruct.APB1CLKDivider = RCC_HCLK_DIV4;
	RCC_ClkInitStruct.APB2CLKDivider = RCC_HCLK_DIV2;

	if (HAL_RCC_ClockConfig(&RCC_ClkInitStruct, FLASH_LATENCY_6) != HAL_OK)
	{
		Error_Handler();
	}

	PeriphClkInitStruct.PeriphClockSelection = RCC_PERIPHCLK_LTDC|RCC_PERIPHCLK_RTC
							  |RCC_PERIPHCLK_USART1|RCC_PERIPHCLK_USART2
							  |RCC_PERIPHCLK_SAI2|RCC_PERIPHCLK_I2C3
							  |RCC_PERIPHCLK_I2C4;
	PeriphClkInitStruct.PLLSAI.PLLSAIN = 57;
	PeriphClkInitStruct.PLLSAI.PLLSAIR = 3;
	PeriphClkInitStruct.PLLSAI.PLLSAIQ = 2;
	PeriphClkInitStruct.PLLSAI.PLLSAIP = RCC_PLLSAIP_DIV2;
	PeriphClkInitStruct.PLLSAIDivQ = 1;
	PeriphClkInitStruct.PLLSAIDivR = RCC_PLLSAIDIVR_4;
	PeriphClkInitStruct.RTCClockSelection = RCC_RTCCLKSOURCE_LSE;
	PeriphClkInitStruct.Sai2ClockSelection = RCC_SAI2CLKSOURCE_PLLSAI;
	PeriphClkInitStruct.Usart1ClockSelection = RCC_USART1CLKSOURCE_PCLK2;
	PeriphClkInitStruct.Usart2ClockSelection = RCC_USART2CLKSOURCE_PCLK1;
	PeriphClkInitStruct.I2c3ClockSelection = RCC_I2C3CLKSOURCE_PCLK1;
	PeriphClkInitStruct.I2c4ClockSelection = RCC_I2C4CLKSOURCE_PCLK1;
	
	if (HAL_RCCEx_PeriphCLKConfig(&PeriphClkInitStruct) != HAL_OK)
	{
		Error_Handler();
	}

	/**Configure the Systick interrupt time 
	*/
	HAL_SYSTICK_Config(HAL_RCC_GetHCLKFreq()/1000);

	/**Configure the Systick 
	*/
	HAL_SYSTICK_CLKSourceConfig(SYSTICK_CLKSOURCE_HCLK);

	/* SysTick_IRQn interrupt configuration */
	HAL_NVIC_SetPriority(SysTick_IRQn, 0, 0);
}


#ifndef	USE_DEBUGGER
void MX_IWDG_Init(void)
{
    hiwdg.Instance = IWDG;
    hiwdg.Init.Prescaler = IWDG_PRESCALER_32;
    hiwdg.Init.Reload = 4095;
    HAL_IWDG_Init(&hiwdg);
}
#endif
void RTC_GetDateTime(RTC_t* data, uint32_t format) 
{
	uint32_t unix;

	/* Get time */
	if (format == RTC_FORMAT_BIN) 
	{
		HAL_RTC_GetTime(&hrtc, &time, RTC_FORMAT_BIN);
	} 
	else 
	{
		HAL_RTC_GetTime(&hrtc, &time, RTC_FORMAT_BCD);
	}
	
	/* Format hours */
	data->hours = time.Hours;
	data->minutes = time.Minutes;
	data->seconds = time.Seconds;
	
	/* Get subseconds */
	data->subseconds = RTC->SSR;
	
	/* Get date */
	if (format == RTC_FORMAT_BIN) 
	{
		HAL_RTC_GetDate(&hrtc, &date, RTC_FORMAT_BIN);
	} 
	else 
	{
		HAL_RTC_GetDate(&hrtc, &date, RTC_FORMAT_BCD);
	}
	
	/* Format date */
	data->year = date.Year;
	data->month = date.Month;
	data->date = date.Date;
	data->day = date.WeekDay;
	
	/* Calculate unix offset */
	unix = RTC_GetUnixTimeStamp(data);
	data->unix = unix;
}


uint32_t RTC_GetUnixTimeStamp(RTC_t* data) 
{
	uint32_t days = 0, seconds = 0;
	uint16_t i;
	uint16_t year = (uint16_t) (data->year + 2000);
	
	/* Year is below offset year */
	if (year < RTC_OFFSET_YEAR) 
	{
		return 0;
	}
	
	/* Days in back years */
	for (i = RTC_OFFSET_YEAR; i < year; i++) 
	{
		days += RTC_DAYS_IN_YEAR(i);
	}
	
	/* Days in current year */
	for (i = 1; i < data->month; i++) 
	{
		days += RTC_Months[RTC_LEAP_YEAR(year)][i - 1];
	}
	
	/* Day starts with 1 */
	days += data->date - 1;
	seconds = days * RTC_SECONDS_PER_DAY;
	seconds += data->hours * RTC_SECONDS_PER_HOUR;
	seconds += data->minutes * RTC_SECONDS_PER_MINUTE;
	seconds += data->seconds;
	
	/* seconds = days * 86400; */
	return seconds;
}


void RTC_GetDateTimeFromUnix(RTC_t* data, uint32_t unix) 
{
	uint16_t year;
	
	/* Store unix time to unix in struct */
	data->unix = unix;
	/* Get seconds from unix */
	data->seconds = unix % 60;
	/* Go to minutes */
	unix /= 60;
	/* Get minutes */
	data->minutes = unix % 60;
	/* Go to hours */
	unix /= 60;
	/* Get hours */
	data->hours = unix % 24;
	/* Go to days */
	unix /= 24;
	
	/* Get week day */
	/* Monday is day one */
	data->day = (unix + 3) % 7 + 1;

	/* Get year */
	year = 1970;
	while (1) 
	{
		if (RTC_LEAP_YEAR(year)) 
		{
			if (unix >= 366) 
			{
				unix -= 366;
			} 
			else 
			{
				break;
			}
		} 
		else if (unix >= 365) 
		{
			unix -= 365;
		} 
		else 
		{
			break;
		}
		year++;
	}
	
	/* Get year in xx format */
	data->year = (uint8_t) (year - 2000);
	
	/* Get month */
	for (data->month = 0; data->month < 12; data->month++) 
	{
		if (RTC_LEAP_YEAR(year)) 
		{
			if (unix >= (uint32_t)RTC_Months[1][data->month]) 
			{
				unix -= RTC_Months[1][data->month];
			}
			else 
			{
				break;
			}
		} 
		else if (unix >= (uint32_t)RTC_Months[0][data->month]) 
		{
			unix -= RTC_Months[0][data->month];
		} 
		else
		{
			break;
		}
	}
	
	/* Get month */
	/* Month starts with 1 */
	data->month++;
	/* Get date */
	/* Date starts with 1 */
	data->date = unix + 1;
}
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

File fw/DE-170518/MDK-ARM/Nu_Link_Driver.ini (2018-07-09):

[Version]
Nu_LinkVersion=V4.7
[Process]
ProcessID=0x00000000
ProcessCreationTime_L=0x00000000
ProcessCreationTime_H=0x00000000
NuLinkID=0x00000000
[ChipSelect]
;ChipName=<NUC1xx|NUC2xx|M05x|N571|N572|Nano100|N512|Mini51|NUC505|General>
ChipName=NUC1xx
[NUC505]
Connect=0
Reset=Autodetect
MaxClock=1MHz
MemoryVerify=0
IOVoltage=3300
Erase=1
Program=1
Verify=1
ResetAndRun=0
EnableFlashBreakpoint=0
EnableLog=0
MemAccessWhileRun=0
RAMForAlgorithmStart=0x20000000
RAMForAlgorithmSize=0x4000
ProgramAlgorithm=NUC505_SPIFLASH.FLM
[NUC4xx]
Connect=0
Reset=Autodetect
MaxClock=1MHz
MemoryVerify=0
IOVoltage=3300
FlashSelect=APROM
Erase=1
Program=1
Verify=1
ResetAndRun=0
EnableFlashBreakpoint=1
EnableLog=0
MemAccessWhileRun=0
RAMForAlgorithmStart=0x20000000
RAMForAlgorithmSize=0x4000
ProgramAlgorithm=NUC400_AP_512.FLM
[NUC2xx]
Connect=0
Reset=Autodetect
MaxClock=1MHz
MemoryVerify=0
IOVoltage=3300
FlashSelect=APROM
Erase=1
Program=1
Verify=1
ResetAndRun=0
EnableFlashBreakpoint=1
EnableLog=0
MemAccessWhileRun=0
RAMForAlgorithmStart=0x20000000
RAMForAlgorithmSize=0x1000
ProgramAlgorithm=NUC200_AP_128.FLM
[NUC126]
Connect=0
Reset=Autodetect
MaxClock=1MHz
MemoryVerify=0
IOVoltage=3300
FlashSelect=APROM
Erase=1
Program=1
Verify=1
ResetAndRun=0
EnableFlashBreakpoint=1
EnableLog=0
MemAccessWhileRun=0
RAMForAlgorithmStart=0x20000000
RAMForAlgorithmSize=0x2000
ProgramAlgorithm=NUC126_AP_256.FLM
[NUC121]
Connect=0
Reset=Autodetect
MaxClock=1MHz
MemoryVerify=0
IOVoltage=3300
FlashSelect=APROM
Erase=1
Program=1
Verify=1
ResetAndRun=0
EnableFlashBreakpoint=1
EnableLog=0
MemAccessWhileRun=0
RAMForAlgorithmStart=0x20000000
RAMForAlgorithmSize=0x1000
ProgramAlgorithm=NUC121_AP_32.FLM
[NUC1xx]
Connect=0
Reset=Autodetect
MaxClock=1MHz
MemoryVerify=0
IOVoltage=3300
FlashSelect=APROM
Erase=1
Program=1
Verify=1
ResetAndRun=0
EnableFlashBreakpoint=1
EnableLog=0
MemAccessWhileRun=0
RAMForAlgorithmStart=0x20000000
RAMForAlgorithmSize=0x1000
ProgramAlgorithm=NUC100_AP_128.FLM
[NUC029]
Connect=0
Reset=Autodetect
MaxClock=1MHz
MemoryVerify=0
IOVoltage=3300
FlashSelect=APROM
Erase=1
Program=1
Verify=1
ResetAndRun=0
EnableFlashBreakpoint=1
EnableLog=0
MemAccessWhileRun=0
RAMForAlgorithmStart=0x20000000
RAMForAlgorithmSize=0x800
ProgramAlgorithm=NUC029_AP_16.FLM
[NM1820]
Connect=0
Reset=Autodetect
MaxClock=1MHz
MemoryVerify=0
IOVoltage=3300
FlashSelect=APROM
Erase=1
Program=1
Verify=1
ResetAndRun=0
EnableFlashBreakpoint=1
EnableLog=0
MemAccessWhileRun=0
RAMForAlgorithmStart=0x20000000
RAMForAlgorithmSize=0x800
ProgramAlgorithm=NM1820_AP_17_5.FLM
[NM1810]
Connect=0
Reset=Autodetect
MaxClock=1MHz
MemoryVerify=0
IOVoltage=3300
FlashSelect=APROM
Erase=1
Program=1
Verify=1
ResetAndRun=0
EnableFlashBreakpoint=1
EnableLog=0
MemAccessWhileRun=0
RAMForAlgorithmStart=0x20000000
RAMForAlgorithmSize=0x800
ProgramAlgorithm=NM1810_AP_29_5.FLM
[NM1500]
Connect=0
Reset=Autodetect
MaxClock=1MHz
MemoryVerify=0
IOVoltage=3300
FlashSelect=APROM
Erase=1
Program=1
Verify=1
ResetAndRun=0
EnableFlashBreakpoint=1
EnableLog=0
MemAccessWhileRun=0
RAMForAlgorithmStart=0x20000000
RAMForAlgorithmSize=0x1000
ProgramAlgorithm=NM1500_AP_128.FLM
[NM1330]
Connect=0
Reset=Autodetect
MaxClock=1MHz
MemoryVerify=0
IOVoltage=3300
FlashSelect=APROM
Erase=1
Program=1
Verify=1
ResetAndRun=0
EnableFlashBreakpoint=1
EnableLog=0
MemAccessWhileRun=0
RAMForAlgorithmStart=0x20000000
RAMForAlgorithmSize=0x1000
ProgramAlgorithm=NM1330_AP_64.FLM
[NM1320]
Connect=0
Reset=Autodetect
MaxClock=1MHz
MemoryVerify=0
IOVoltage=3300
FlashSelect=APROM
Erase=1
Program=1
Verify=1
ResetAndRun=0
EnableFlashBreakpoint=1
EnableLog=0
MemAccessWhileRun=0
RAMForAlgorithmStart=0x20000000
RAMForAlgorithmSize=0x1000
ProgramAlgorithm=NM1320_AP_32.FLM
[NM1200]
Connect=0
Reset=Autodetect
MaxClock=1MHz
MemoryVerify=0
IOVoltage=3300
FlashSelect=APROM
Erase=1
Program=1
Verify=1
ResetAndRun=0
EnableFlashBreakpoint=1
EnableLog=0
MemAccessWhileRun=0
RAMForAlgorithmStart=0x20000000
RAMForAlgorithmSize=0x800
ProgramAlgorithm=NM1200_AP_8.FLM
[NM1120]
Connect=0
Reset=Autodetect
MaxClock=1MHz
MemoryVerify=0
IOVoltage=3300
FlashSelect=APROM
Erase=1
Program=1
Verify=1
ResetAndRun=0
EnableFlashBreakpoint=1
EnableLog=0
MemAccessWhileRun=0
RAMForAlgorithmStart=0x20000000
RAMForAlgorithmSize=0x800
ProgramAlgorithm=NM1120_AP_29_5.FLM
[Nano103]
Connect=0
Reset=Autodetect
MaxClock=1MHz
MemoryVerify=0
IOVoltage=3300
FlashSelect=APROM
Erase=1
Program=1
Verify=1
ResetAndRun=0
EnableFlashBreakpoint=1
EnableLog=0
MemAccessWhileRun=0
RAMForAlgorithmStart=0x20000000
RAMForAlgorithmSize=0x1000
ProgramAlgorithm=Nano103_AP_64.FLM
[Nano100]
Connect=0
Reset=Autodetect
MaxClock=1MHz
MemoryVerify=0
IOVoltage=3300
FlashSelect=APROM
Erase=1
Program=1
Verify=1
ResetAndRun=0
EnableFlashBreakpoint=1
EnableLog=0
MemAccessWhileRun=0
RAMForAlgorithmStart=0x20000000
RAMForAlgorithmSize=0x1000
ProgramAlgorithm=Nano100_AP_64.FLM
[N576]
Connect=0
Reset=Autodetect
MaxClock=1MHz
MemoryVerify=0
IOVoltage=3300
FlashSelect=APROM
Erase=1
Program=1
Verify=1
ResetAndRun=0
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

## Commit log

2018-07-09 add last project files
    [DE-020717.GBL, DE-020717.GBO, DE-020717.GBP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]
2018-07-10 MDK-ARM build

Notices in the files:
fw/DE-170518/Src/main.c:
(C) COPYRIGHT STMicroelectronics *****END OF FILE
